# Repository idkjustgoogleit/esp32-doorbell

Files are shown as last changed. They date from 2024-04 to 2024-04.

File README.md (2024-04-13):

<h1>ESP32 S3 Doorbell via ESPHome & HA</h1>
<p align="center">
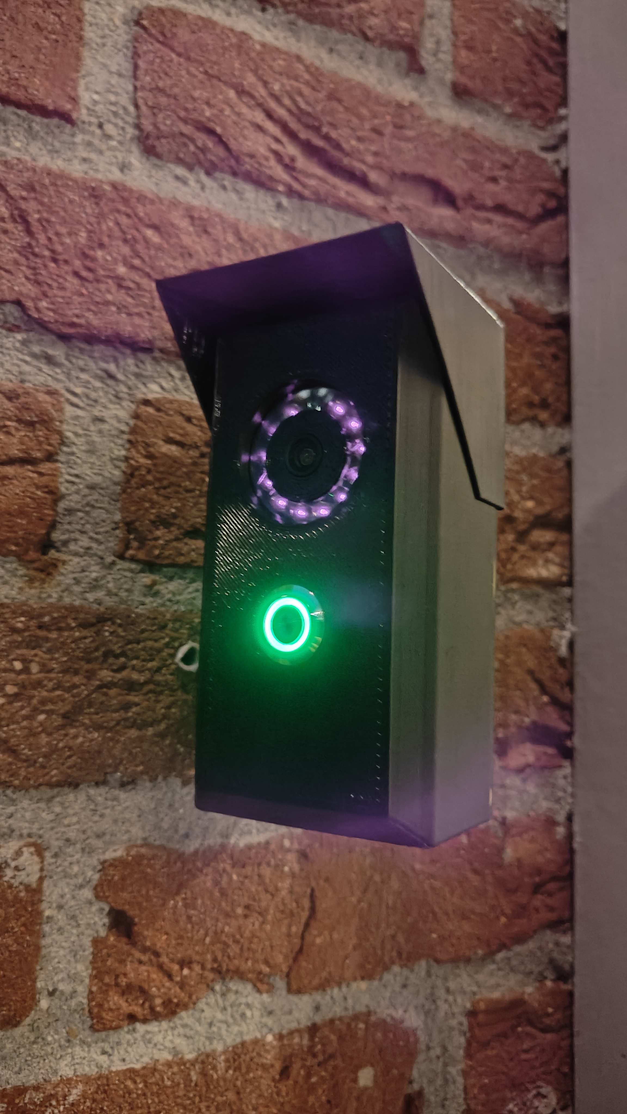
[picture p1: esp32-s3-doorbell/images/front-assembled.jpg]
  
</p>
<p>Couldn't find a generic DIY Doorbell with a nice angle, modular and easy to print; so made myself (another) one.&nbsp;</p>
<p>This is an updated version which I made before but didn't have IR Night-vision, and was not so stable for 24/7 video streaming because of an overheating camera module (should have used a heatsink on that one too):</p>
<p>
  <a href="https://www.printables.com/model/667022-esp32-doorbell-and-weatherstation" target="_blank" rel="ugc">https://www.printables.com/model/667022-esp32-doorbell-and-weatherstation</a>&nbsp;
</p>
<p>Like the other design, this is also not waterproof so I put a rubber band in between, because why not. There is a smoll roof included in the design just to be safe I guess.</p>
<p>Print with PETG because I don't know how direct sunlight would affect PLA.</p>
<p>
  <strong>Wiring:</strong>
</p>
<p align="center">
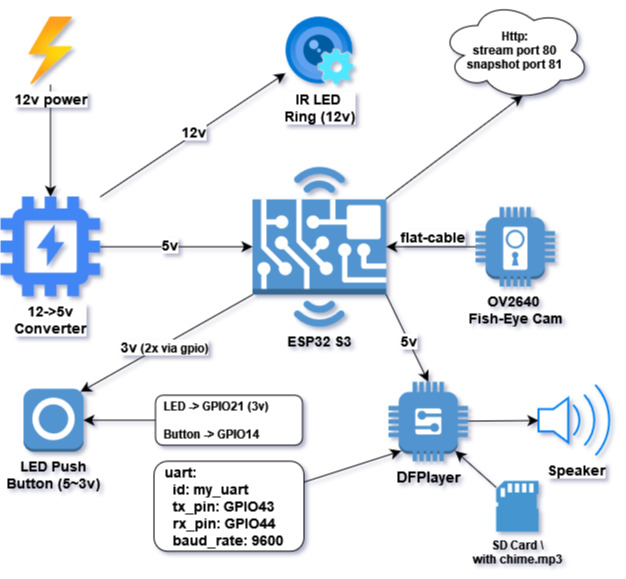
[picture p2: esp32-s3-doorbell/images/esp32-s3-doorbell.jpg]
  
</p>
<p>
  <strong>Parts &amp; Requirements list:</strong>
</p>
<ul>
  <li>Home Assistant! <ul>
      <li>With preferably <a href="https://www.home-assistant.io/integrations/motioneye/" target="_blank" rel="ugc">MotionEye </a>as a light NVR software for recording </li>
      <li>With <a href="https://esphome.io/guides/getting_started_hassio.html" target="_blank" rel="ugc">ESPHome</a>: </li>
      <li>My YAML configuration of the ESP32 S3 via ESPHOME: <a href="https://github.com/idkjustgoogleit/esp32/blob/main/esp32-s3-doorbell/esp32-s3-doorbell_config" target="_blank" rel="ugc">GitHUB</a>
        <i>( ←this took a lot of time to figure out, enjoy!)</i>
        <br>&nbsp;
      </li>
    </ul>
  </li>
  <li>Soldering iron! (don't use the cheap ones!)</li>
  <li>At least 4 WaGo connectors, or solder cables if you'd prefer</li>
  <li>12v adapter if you want to use night vision, otherwise a good 5v usb chager.</li>
  <li>A few M3 bolts + nuts + screws</li>
  <li>Rubber band (optional)</li>
  <li>16mm metal push button (5v): <a href="https://nl.aliexpress.com/item/4001291695467.html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" target="_blank" rel="ugc">AliExpress</a>
  </li>
  <li>DuPont cables</li>
  <li>ESP32 S3 Freenove with CAM support: <a href="https://nl.aliexpress.com/item/1005004339923548.html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" target="_blank" rel="ugc">AliExpress</a>
  </li>
  <li>Wide angle camera with long (75mm) cable, like this one:&nbsp; <a href="https://nl.aliexpress.com/item/1005002947160929.html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" target="_blank" rel="ugc">AliExpress</a>
    <br>&nbsp;
  </li>
  <li>( <i>This is a tricky one</i>) Transparent flat sheet of plastic; you will need to (eyeball) cut this into a small square with a hole in the middle, which then will serve as protection for the IR LED Ring and ofc the internals of the case. I used a plastic transparent candy box, and re-purposed it accordingly. OR buy this and make your own camera holder: <a href="https://nl.aliexpress.com/item/32815931704.html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" target="_blank" rel="ugc">AliExpress</a>
    <br>&nbsp;
  </li>
  <li>
    <strong>VERY IMPORTANT:</strong>
    <br>
    <i>You <strong>WILL </strong>NEED a small heatsink </i>to put behind the camera module because they heat up and die. I used an aluminum heatsink which I had laying around for a generic raspberry pi. <br>&nbsp;
  </li>
  <li>
    <strong>IR Night-vision LED Ring:</strong>
    <br>I used this but is not sold anymore: <a href="https://nl.aliexpress.com/item/32861366234.html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" target="_blank" rel="ugc">AlieExpress</a>
    <ul>
      <li>
        <strong>Buy this instead</strong> because it has same specs and dimensions: <a href="https://nl.aliexpress.com/item/1005004141393390.html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" target="_blank" rel="ugc">AliExpress</a>
        <br>&nbsp;
      </li>
      <li>When using these you will need to use a 12v to 5v buck converter to power the 12v IR Led ring AND the ESP32 and etc at 5v at the same time: <a href="https://nl.aliexpress.com/item/32861366234.html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" target="_blank" rel="ugc">AliExpress</a>
      </li>
    </ul>
  </li>
</ul>
<p>
  <strong>Ringer: </strong>The <a href="https://github.com/idkjustgoogleit/esp32/blob/main/esp32-s3-doorbell/esp32-s3-doorbell_config" target="_blank" rel="ugc">YAML Config included</a> relies on a <a href="https://esphome.io/components/dfplayer.html" target="_blank" rel="ugc">DFPlayer module</a> to ring a doorbell chime through a small speaker. Whenever the doorbell button is pressed, the metal push button led light will flash a few times AND will play a mp3 file on the SD-Card of the DFPlayer module:
</p>
<ul>
  <li>DFPlayer module: <a href="https://nl.aliexpress.com/item/1005006027775709.html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" target="_blank" rel="ugc">AliExpress</a>
  </li>
  <li>Small (intercom) speaker: <a href="https://nl.aliexpress.com/item/1005006056453298.html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" target="_blank" rel="ugc">AliExpress</a>
  </li>
</ul>
<p>&nbsp;</p>
<p>
  <i>
    <strong>Side notes</strong>
  </i>: the IR Night vision LED Ring is too strong :) SO I have solved this by <a href="https://github.com/esphome/esphome/pull/3090" target="_blank" rel="ugc">changing the camera image settings on the fly</a> before and after sunset. This is done via an HomeAssistant automation and 2 scripts:
</p>
<ul>
  <li>After sunrise → trigger automation → set daylight mode using following script: <a href="https://github.com/idkjustgoogleit/esp32/blob/main/esp32-s3-doorbell/HA_Script_doorbell_cam_set_daylight" target="_blank" rel="ugc">HA Script (github)</a>
  </li>
  <li>After sunset → trigger automation → set night mode using following script: <a href="https://github.com/idkjustgoogleit/esp32/blob/main/esp32-s3-doorbell/HA_Script_doorbell_cam_set_night" target="_blank" rel="ugc">HA Script (github)</a>
  </li>
</ul>
<p>As you can see in the images, I have added a preview of the HomeAssistant page which shows the stream and some details. On that page I have added 2 buttons to change the image settings just in case the automation triggers above did not work.</p>
<p>&nbsp;</p>

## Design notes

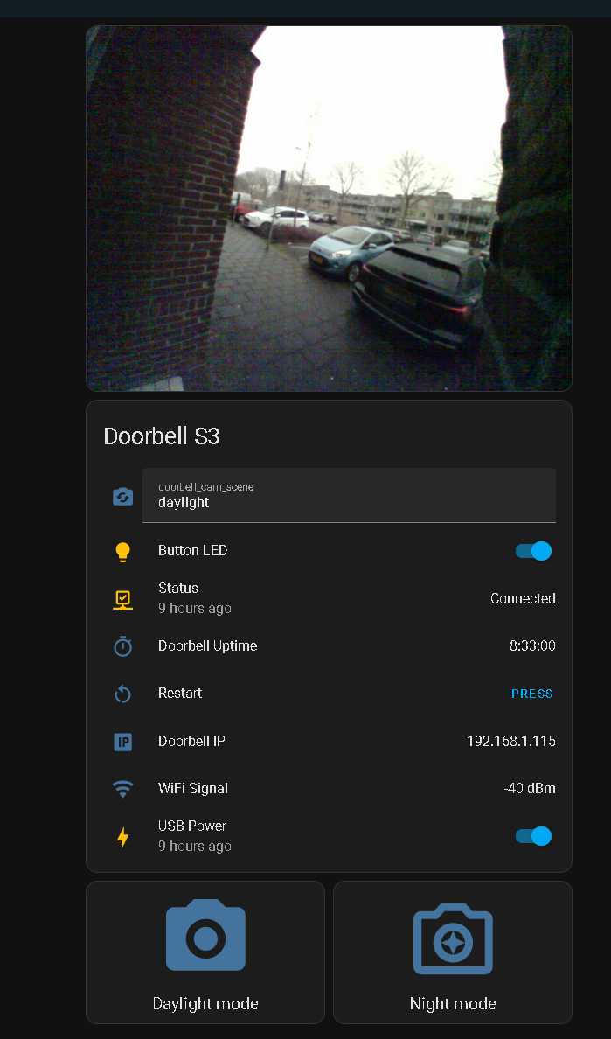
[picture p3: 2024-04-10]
esp32-s3-doorbell/images/homeassistant preview.png

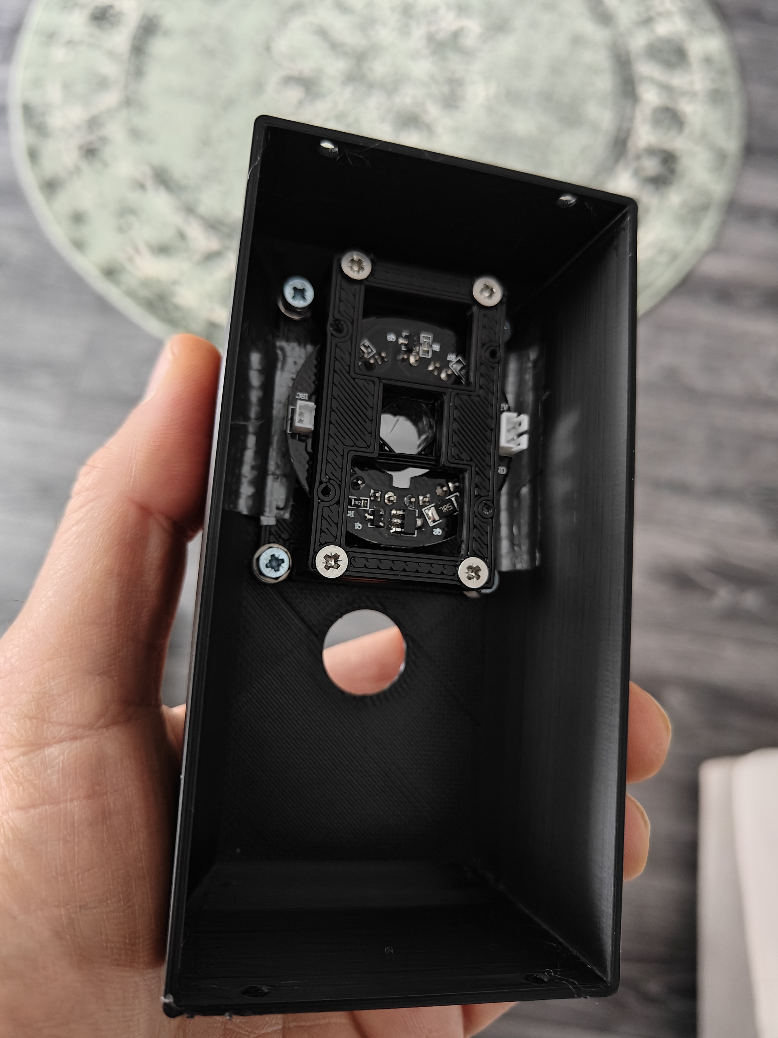
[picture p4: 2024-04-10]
esp32-s3-doorbell/images/empty-inside.jpg

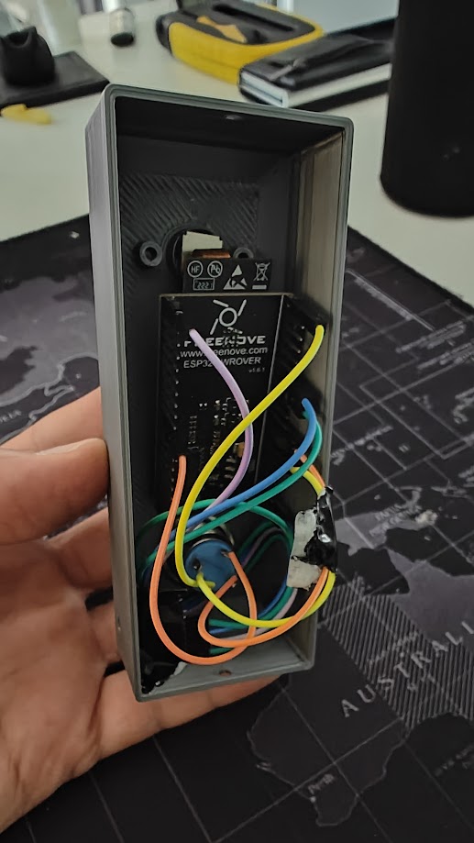
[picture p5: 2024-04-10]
esp32-wrover-doorbell/images/organs.jpg

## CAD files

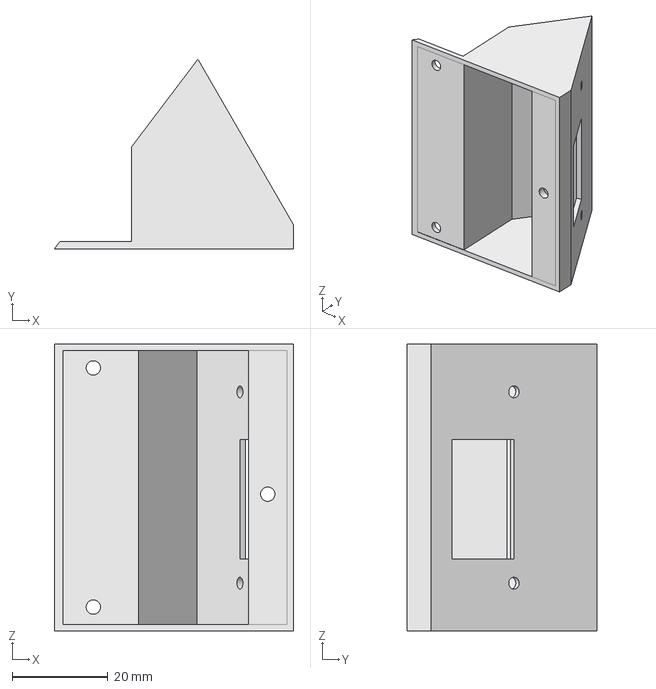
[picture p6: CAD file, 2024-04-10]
esp32-s3-doorbell/FreeCAD-designs/doorbell-mount-v3.fcstd
50.0 x 39.6 x 60.0 mm

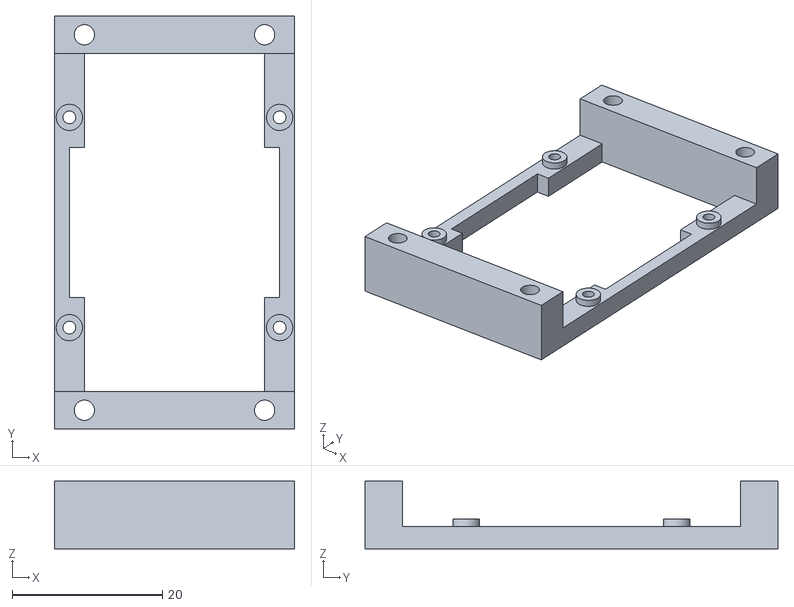
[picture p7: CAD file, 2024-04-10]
esp32-s3-doorbell/STL/ir-plate-holder-v01.stl
32.0 x 55.0 x 9.00

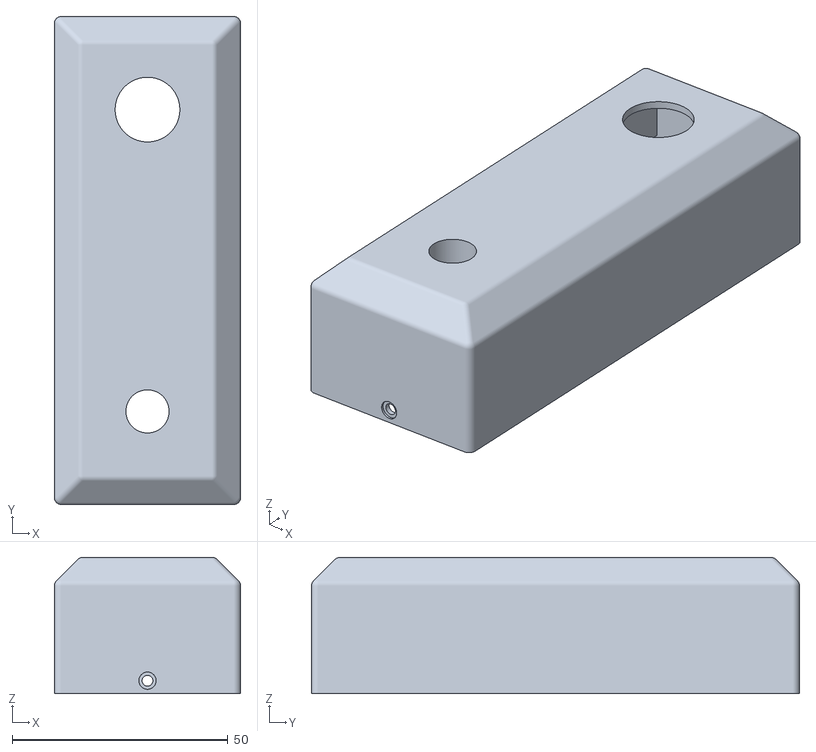
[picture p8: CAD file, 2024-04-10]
esp32-wrover-doorbell/STL/frontpanel-v1.stl
43.2 x 113.2 x 31.6

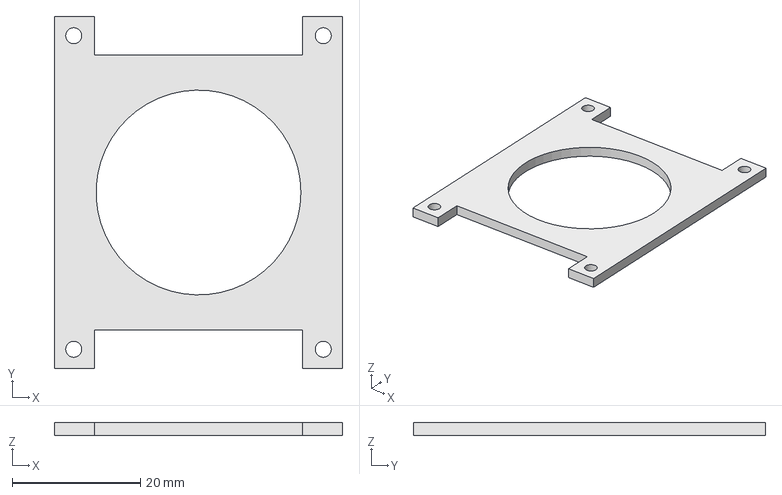
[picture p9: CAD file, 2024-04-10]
esp32-s3-doorbell/FreeCAD-designs/lens-holders-v02.fcstd
45.0 x 55.0 x 2.00 mm

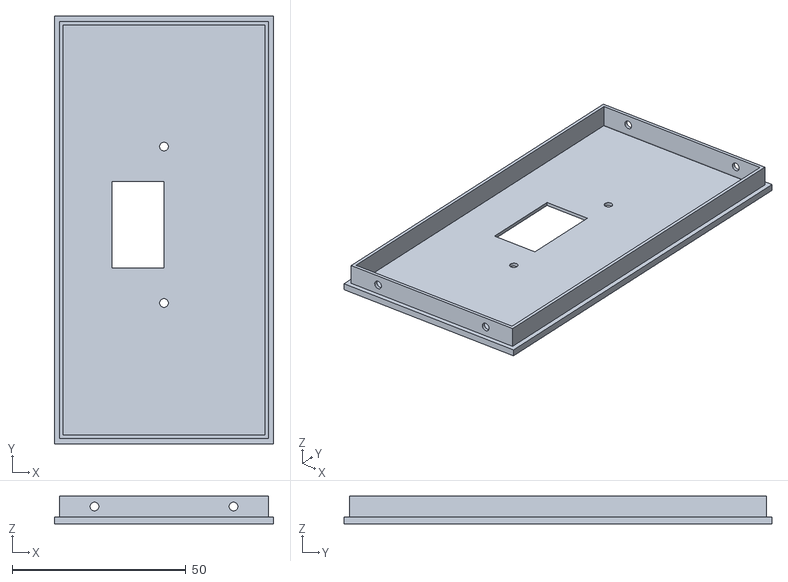
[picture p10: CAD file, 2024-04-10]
esp32-s3-doorbell/STL/backplate-v03.stl
63.0 x 123.0 x 8.00

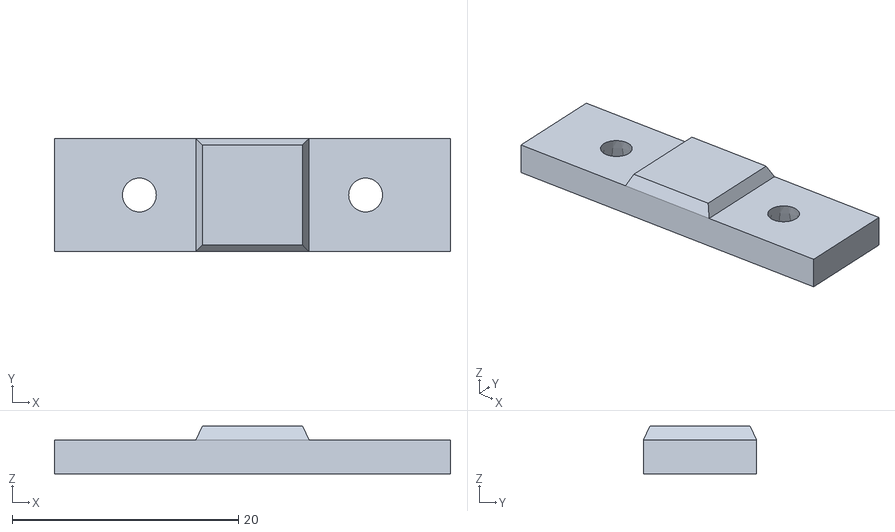
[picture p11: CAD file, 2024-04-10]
esp32-wrover-doorbell/STL/front-camera-holder-v1.stl
35.0 x 10.0 x 4.20

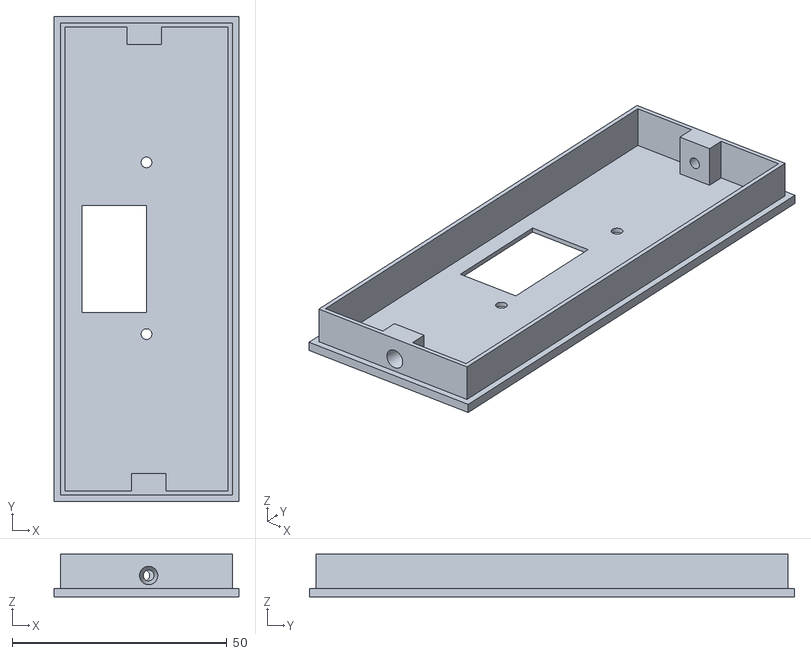
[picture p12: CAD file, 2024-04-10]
esp32-wrover-doorbell/STL/square-back-plate-v3.stl
43.0 x 113.0 x 10.0

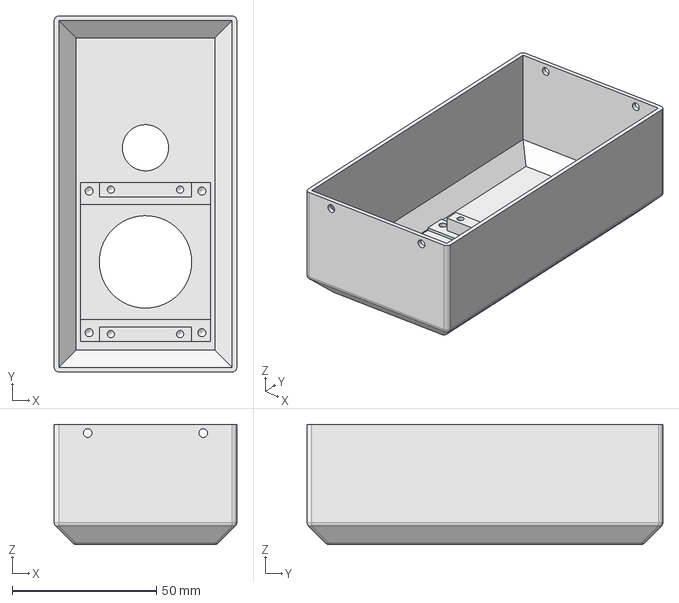
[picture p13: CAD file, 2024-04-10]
esp32-s3-doorbell/FreeCAD-designs/frontpanel-v02.fcstd
63.2 x 123.2 x 41.6 mm

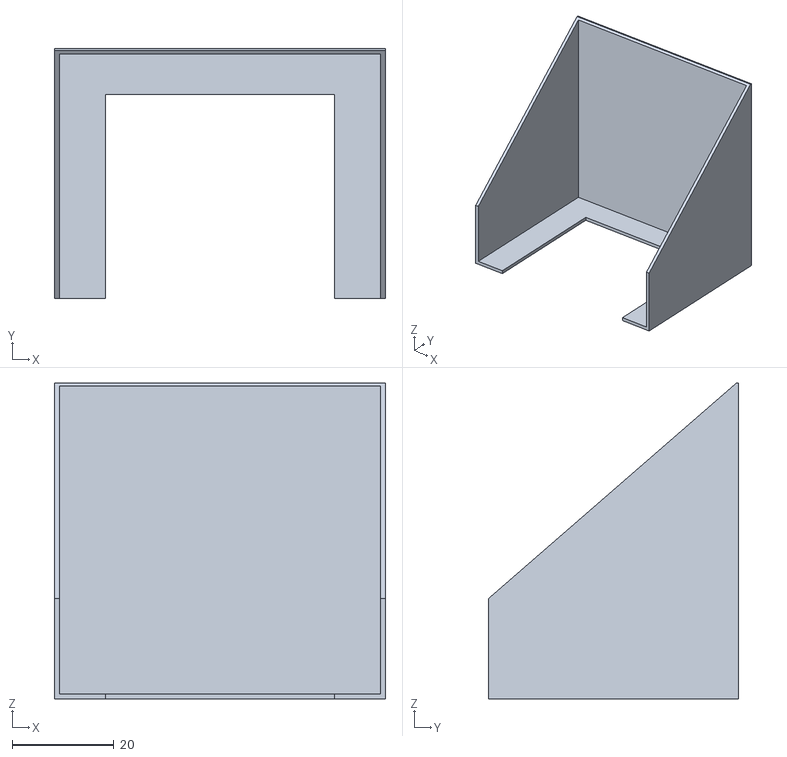
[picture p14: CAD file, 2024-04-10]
esp32-s3-doorbell/STL/cover-v01.stl
65.0 x 49.0 x 62.0

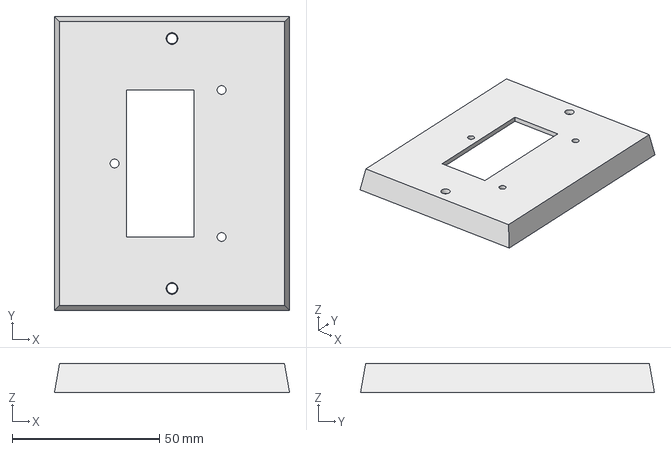
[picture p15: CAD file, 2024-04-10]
esp32-s3-doorbell/FreeCAD-designs/wall-plate-v02.fcstd
80.0 x 100.0 x 10.0 mm

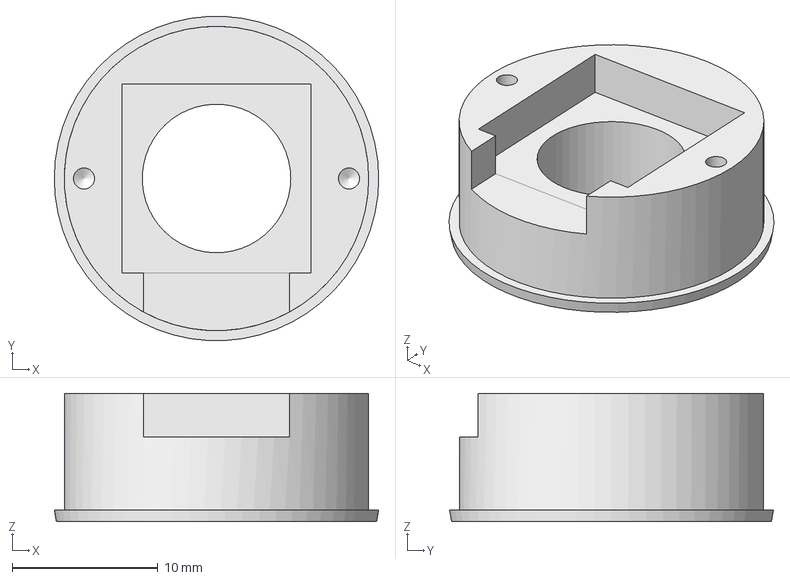
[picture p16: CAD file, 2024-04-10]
esp32-s3-doorbell/FreeCAD-designs/cam-holder-v041.fcstd
22.3 x 22.2 x 8.80 mm

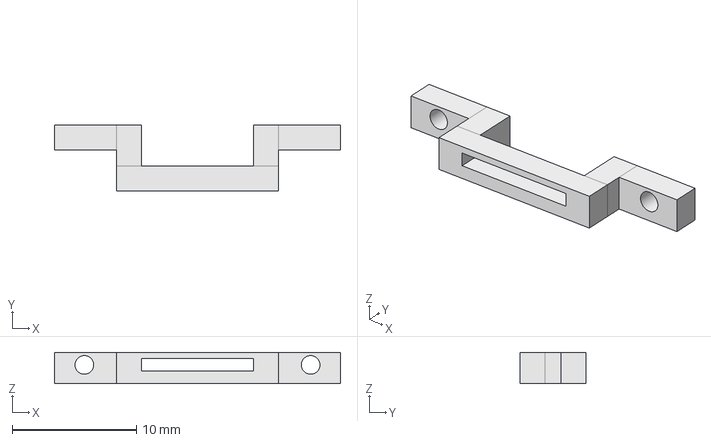
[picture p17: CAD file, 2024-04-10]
esp32-s3-doorbell/FreeCAD-designs/cam-back-plate-v02.fcstd
23.0 x 5.30 x 2.50 mm

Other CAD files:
esp32-s3-doorbell/FreeCAD-designs/backplate-v03.fcstd
esp32-s3-doorbell/STL/lens-holders-v02.stl
esp32-wrover-doorbell/STL/doorbell-mount-v3-body.stl
esp32-s3-doorbell/STL/frontpanel-v02.stl
esp32-wrover-doorbell/STL/wall-plate-v02.stl
esp32-s3-doorbell/STL/cam-holder-v041.stl
esp32-s3-doorbell/FreeCAD-designs/cover-v01.fcstd
esp32-s3-doorbell/FreeCAD-designs/ir-plate-holder-v01.fcstd
esp32-s3-doorbell/STL/cam-back-plate-v02.stl

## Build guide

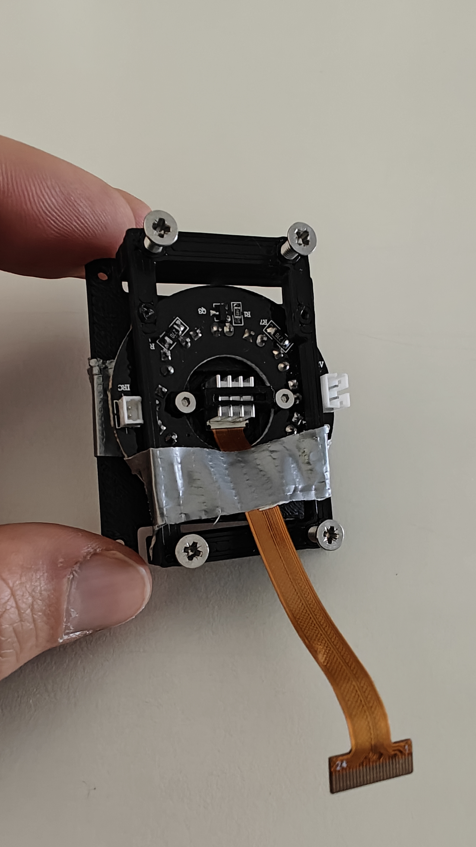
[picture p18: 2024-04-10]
esp32-s3-doorbell/images/cam-lens-assembled-backside.jpg

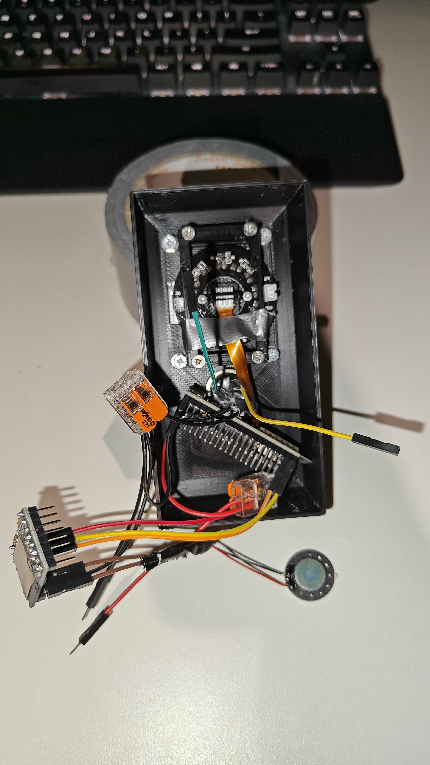
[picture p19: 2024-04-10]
esp32-s3-doorbell/images/organs-assembly.jpg

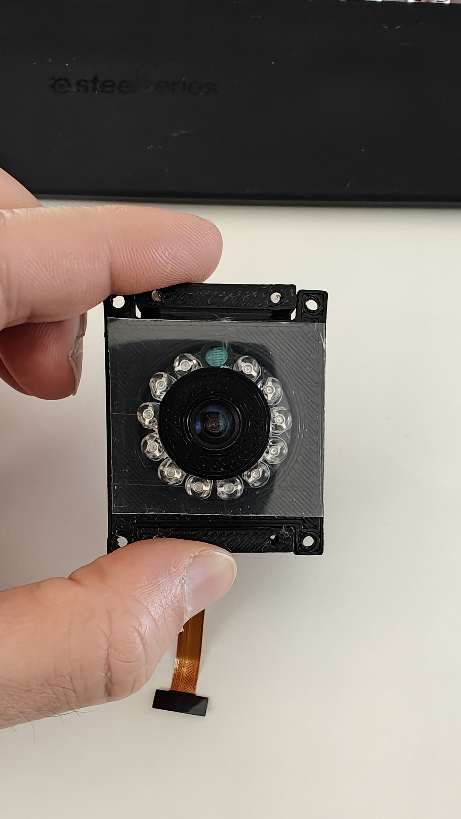
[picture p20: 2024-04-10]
esp32-s3-doorbell/images/cam-lens-assembled.jpg

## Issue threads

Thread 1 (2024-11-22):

Night Vision

matthias1403, 2024-11-22:
Hi,

I have already a similar doorbell and would like to "upgrade" it with night vision. Don't you need an IR shutter that the camera is able to capture IR? How is the night view if you keep the IR filter?

Thanks & Best regard, Matthias

idkjustgoogleit, 2024-11-23:
Hi Matthias,

In the parts list I had added a fish eye lens camera which just works. That one doesn't have a certain filter, and at the same time during daylight the image is very good without color issues for my frontdoor usage. This could probably be different in other lighting.

However I'm not sure if the one I have is very sensitive to ir light, because the ir led ring I use appears to light up the person in front of the camera too much which I counteract with a different camera image setting for Night usage. Otherwise the image is unusable.

If I would redo, I would just do a few ir leds instead of a led ring with 12+ leds like I have now :)

But I don't know (yet) how to make e.g. a model with just 2 it ir leds operating at 940nm wave length. Also to make those 2 leds to work on 5v instead of 12v would cutout the need of a step down converter.

Hope this gives some insight.

Good luck!

Closed 2024-11-23.

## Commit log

2024-03-22 Create esp32-s3-doorbell
2024-03-22 Create esp32-doorbell_config
